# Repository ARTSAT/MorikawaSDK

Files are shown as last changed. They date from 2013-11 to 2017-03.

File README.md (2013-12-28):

MorikawaSDK
===========

An arduino base application programming environment for satellite's mission.

currently supported APIs:

```cpp
// singleton design
static & getInstance(void);

// memory environment and memory state
static TSTError getMemorySpec(MemorySpec* result);
static TSTError getMemoryInfo(MemoryInfo* result);
static TSTError getMemoryLog(MemoryInfo* result);
static void saveMemoryLog(void);

// self test
static TSTError getSelfTestLog(SelfTestLog* result);
static void eraseSelfTestLog(void);

// memory size information
static unsigned long getSizeEEPROM(void);
static unsigned long getSizeSharedMemory(void);
static unsigned long getSizeFRAM(void);
static unsigned long getSizeFlashROM(void);
static unsigned int getPageSizeEEPROM(void);
static unsigned int getPageSizeSharedMemory(void);
static unsigned int getPageSizeFRAM(void);
static unsigned int getPageSizeFlashROM(void);
static unsigned long getSectorSizeEEPROM(void);
static unsigned long getSectorSizeSharedMemory(void);
static unsigned long getSectorSizeFRAM(void);
static unsigned long getSectorSizeFlashROM(void);

// camera format information
static TSTError getCameraFormat(CameraType mode, CameraFormat* result);

// boot parameter
unsigned long getBootTime(void) const;
unsigned char getBootCount(void) const;
unsigned char getBootMode(void) const;

// peripheral parameter
TSTError getParamNote(NoteParam* result);
TSTError getParamMorse(MorseParam* result);
TSTError getParamDigitalker(DigitalkerParam* result);
TSTError getParamCamera(CameraParam* result);

// telemetry data
TSTError getTelemetryTime(TimeType type, unsigned long* result) const;
TSTError getTelemetryVoltage(VoltageType type, unsigned char* result) const;
TSTError getTelemetryVoltage(VoltageType type, double* result) const;
TSTError getTelemetryCurrent(CurrentType type, unsigned char* result) const;
TSTError getTelemetryCurrent(CurrentType type, double* result) const;
TSTError getTelemetryTemperature(TemperatureType type, unsigned char* result) const;
TSTError getTelemetryTemperature(TemperatureType type, double* result) const;
TSTError getTelemetryGyro(GyroType type, unsigned char* result) const;
TSTError getTelemetryGyro(GyroType type, double* result) const;
TSTError getTelemetryMagnet(MagnetType type, unsigned char* result) const;
TSTError getTelemetryMagnet(MagnetType type, double* result) const;

// FlashROM mode
TSTError setFlashROMEraseMode(bool param);
bool getFlashROMEraseMode(void) const;

// shared memory text setter and text getter
TSTError setText(TextType index, char const* text, int length = -1);
TSTError setTextPGM(TextType index, char const PROGMEM* text, int length = -1);
TSTError getText(TextType index, char* text, unsigned int length, int* result = NULL);

// peripheral LED device
TSTError setLED(LEDType index, unsigned char pwm);
unsigned char getLED(LEDType index) const;

// peripheral mode
TSTError setNoteBPM(int param = -1);
int getNoteBPM(void) const;
TSTError setMorseWPM(int param = -1);
int getMorseWPM(void) const;
TSTError setSpeakAsyncMode(bool param);
bool getSpeakAsyncMode(void) const;

// validation
bool isValid(void) const;
bool isValidSharedMemory(void) const;
bool isValidFRAM(void) const;
bool isValidFlashROM(void) const;
bool isValidLED(void) const;
bool isValidTone(void) const;
bool isValidDigitalker(void) const;
bool isValidCamera(void) const;

// status
TSTError isBusyDigitalker(bool* result) const;
bool hasTelemetryUpdate(void) const;
bool hasAbnormalShutdown(void) const;

// core function
TSTError setup(void);
void cleanup(void);
static void shutdown(void);
void loop(void);

// EEPROM
static TSTError writeEEPROM(unsigned long address, void const* data, unsigned int size, unsigned int* result = NULL);
static TSTError writeEEPROMPGM(unsigned long address, void const PROGMEM* data, unsigned int size, unsigned int* result = NULL);
static TSTError readEEPROM(unsigned long address, void* data, unsigned int size, unsigned int* result = NULL);
static TSTError formatEEPROM(void);

// Shared Memory
TSTError writeSharedMemory(unsigned long address, void const* data, unsigned int size, unsigned int* result = NULL);
TSTError writeSharedMemoryPGM(unsigned long address, void const PROGMEM* data, unsigned int size, unsigned int* result = NULL);
TSTError readSharedMemory(unsigned long address, void* data, unsigned int size, unsigned int* result = NULL);
TSTError formatSharedMemory(void);

// FRAM
TSTError writeFRAM(unsigned long address, void const* data, unsigned int size, unsigned int* result = NULL);
TSTError writeFRAMPGM(unsigned long address, void const PROGMEM* data, unsigned int size, unsigned int* result = NULL);
TSTError readFRAM(unsigned long address, void* data, unsigned int size, unsigned int* result = NULL);
TSTError formatFRAM(void);

// FlashROM
TSTError writeFlashROM(unsigned long address, void const* data, unsigned int size, unsigned int* result = NULL);
TSTError writeFlashROMPGM(unsigned long address, void const PROGMEM* data, unsigned int size, unsigned int* result = NULL);
TSTError readFlashROM(unsigned long address, void* data, unsigned int size, unsigned int* result = NULL);
TSTError formatFlashROM(void);

// note and morse
TSTError playFrequency(FrequencyType frequency, unsigned long duration);
TSTError playFrequency(FrequencySequence const* sequence, int length = -1);
TSTError playFrequencyPGM(FrequencySequence const PROGMEM* sequence, int length = -1);
TSTError playNote(NoteType note, DurationType duration, QualifierType qualifier = QUALIFIER_NONE);
TSTError playNote(NoteSequence const* sequence, int length = -1);
TSTError playNotePGM(NoteSequence const PROGMEM* sequence, int length = -1);
TSTError playMorse(NoteType note, char character);
TSTError playMorse(NoteType note, char const* sequence, int length = -1);
TSTError playMorsePGM(NoteType note, char const PROGMEM* sequence, int length = -1);

// digitalker
TSTError speakPhrase(char const* phrase, int length = -1);
TSTError speakPhrasePGM(char const PROGMEM* phrase, int length = -1);
TSTError waitPhrase(void);
TSTError stopPhrase(void);

// camera
TSTError snapshotCamera(CameraType mode, StorageType storage, unsigned long address, unsigned long size, unsigned long* result);

// data compression / decompression
TSTError freezeFastLZ(StorageType istorage, unsigned long iaddress, unsigned long isize, StorageType ostorage, unsigned long oaddress, unsigned long osize, StorageType wstorage, unsigned long waddress, unsigned long wsize, unsigned long* result);
TSTError meltFastLZ(StorageType istorage, unsigned long iaddress, unsigned long isize, StorageType ostorage, unsigned long oaddress, unsigned long osize, unsigned long* result);

// audio power control
TSTError enableAudioBus(void);
void disableAudioBus(void);
```

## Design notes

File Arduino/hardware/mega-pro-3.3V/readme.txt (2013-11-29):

Instructions to have the Mega Pro 3.3V show up in the Arduino device list. 
 
1) Download the latest mega_pro_3.3V zip file and extract it.	
2) You will need to be using a recent version of the Arduino environment, version 18 or later.
3) Create a 'hardware' directory inside your sketches folder. 
4) Copy the mega_pro_3.3V directory into the hardware directory.
5) Restart the Arduino software. New boards will appear in the Tools > Board menu.

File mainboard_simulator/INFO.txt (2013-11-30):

If you want to use MainBoard simulator, please see

https://github.com/ARTSAT/ground_station/tree/master/openFrameworks-osx/MainBoardSimulator

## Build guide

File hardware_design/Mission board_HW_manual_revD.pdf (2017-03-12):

# ARTSAT Mission board Developer’s Manual

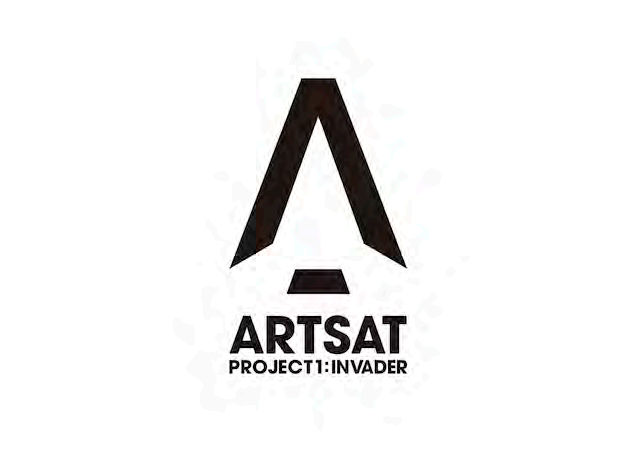
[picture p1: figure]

# Code name: MORIKAWA

# Flight Model

2017/03/12

## Kent Nakazawa (kent_n@outlook.com)

## ・INVADER 衛星(CO-77)の Arduino 互換ミッション機器

## ・Arduino IDE によるアプリケーション開発(MORIKAWA SDK)

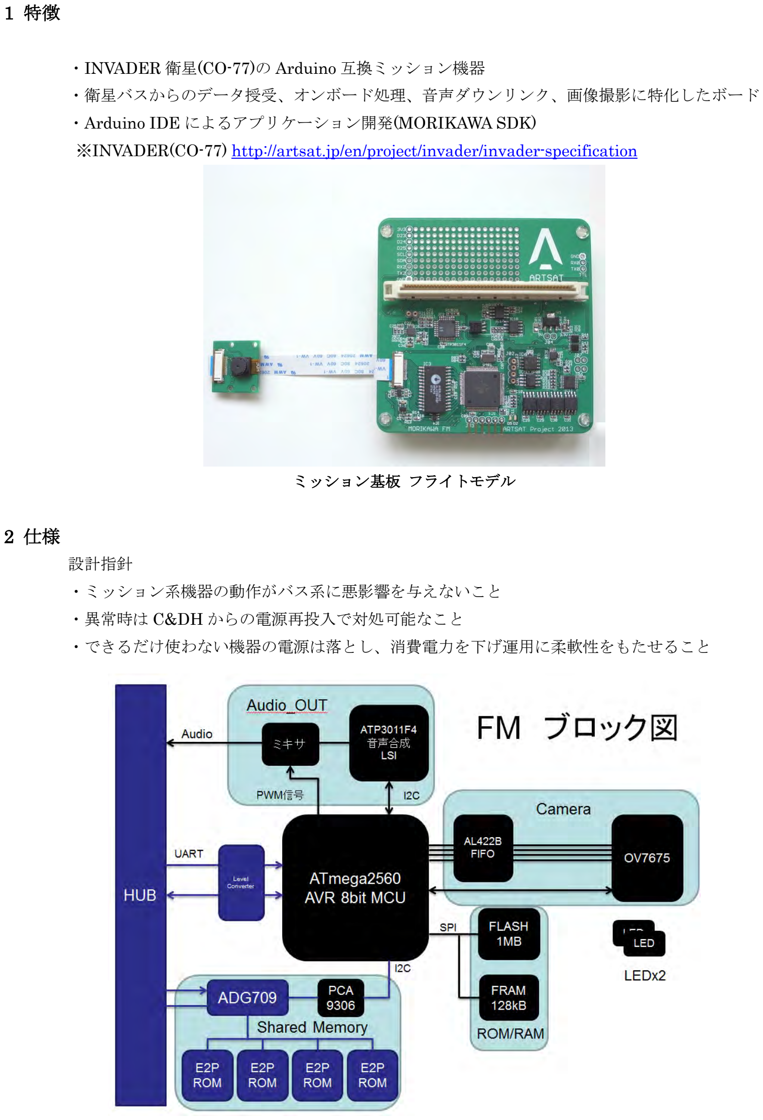
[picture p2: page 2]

1 特徴

・衛星バスからのデータ授受、オンボード処理、音声ダウンリンク、画像撮影に特化したボード

## ※INVADER(CO-77) http://artsat.jp/en/project/invader/invader-specification

ミッション基板 フライトモデル

2 仕様

設計指針
・ミッション系機器の動作がバス系に悪影響を与えないこと
・異常時は C&DH からの電源再投入で対処可能なこと

・できるだけ使わない機器の電源は落とし、消費電力を下げ運用に柔軟性をもたせること

## 2.1 MCU ・ATmega2560(RAM8kB,ROM256kB) 動作周波数 8MHz タイプ

・同期/非同期シリアル I2C_1ch, SPI_1ch,UART_4ch,
2.2 カメラモジュール
・OV7670 CMOS フライトモデルではレンズ一体型モジュールを使用。

## ・AL422B VGA FIFO ・12 / 24MHz クロック発振器 FM は 12MHzOSC

・ピン接続仕様は市販の FIFO 付きカメラモジュールと互換 ・カメラ用素子(モジュール、FIFO)の電源は未使用時に OFF

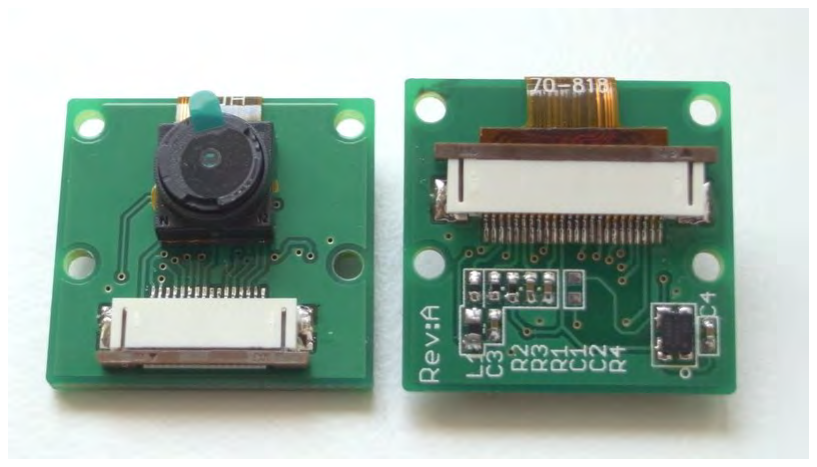
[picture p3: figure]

カメラモジュール 子基板

## 2.3 音声合成 LSI ATP3011F4 日本語音声合成 IC 通信: I2C

## 2.4 不揮発性 RAM ・SPI FRAM 128kB FM25V10

・消費電流が少なく、1 バイト単位でのアクセスが可能な不揮発性メモリ ・M25P80 とピン互換
・Flash や EEPROM へ保存する前のバッファメモリ等
2.5 大容量 ROM ストレージ

## ・SPI Flash メモリ 1MB M25P80

・Flash メモリ。画像、処理結果データの保存先として確保 2.8 共有メモリ

## ・EEPROM(24LC1025) x4 個 電源ドメインは 5V 系

・Main 系が、マルチプレクサ ADG709 によりアクセス権を設定 (LOW=バス系、HIGH=ミッション 系 切り替えラインはプルダウン) し、Mission 側に切り替え権は無い ・基板上のジャンパピンにより単独でアクセス可能 (開発用機能)

バス接続時、フライト時はジャンパピンを外すこと

## 2.6 LED x2 ・ATmega2560 へ接続(正論理)

・主にステータス確認用

2.7 INVADER バス接続用インターフェース

## ・バスは 5V 系 Mission は 3.3V 系

・共有メモリ、バス温度センサは 5V 系、C&DH 電源で動作 ・2 電源バスバッファにより電圧変換(UART、共有メモリ I2C)

3 開発環境

3.1 ソフトウェア開発環境

機器一覧

## ・USB-Serial 変換器/プログラマ https://www.sparkfun.com/products/9873

・リセット(DTR)がついた TTL レベル UART 接続 5V 供給できるもの

## ・PC/Mac/Linux ・既製品の Arduino ボード（ArduinoISP として使用）

・Arduino IDE(1.0.6) ※最新の IDE ではボード定義の追加が難しいため、1.0.6 での構築を推奨

## https://www.arduino.cc/en/Main/OldSoftwareReleases#previous

## 3.2 Arduino IDE 設定 (ArduinoIDE バージョン 1.0.6)

・Arduino IDE をインストールする
・MorikawaSDK に必要なファイルをダウンロードする。

## https://github.com/ARTSAT/MorikawaSDK をダウンロードし、 Arduino ディレクトリ内の二つのディレクトリ（libraries, hardware）を ArduinoIDE のスケッチ保存フォルダ（デフォルトでは documents/Arduino 内）に

入れる。
・ArduinoIDE を立ち上げ、ツール/board からボード選択リストを開き、

## Mega Pro 2560V 3.3V を選択

3.3 AVR ブートローダ設定

## ATmega2560 8MHz 版ブートローダの設定

・MORIKAWA にシリアルブートローダーを設定することで、シリアルポートからスケッチをアップロ

ードできる
・書き込みは ICSP という方式で、Arduino ボードをライターとして使用する手法を使う ・ICSP 用 4 ピン端子(J02 )を J02 に設けており、Arduino ISP 等で書き込みが可能

書き込みの流れは以下のサイトを参考にする

## https://www.arduino.cc/en/Tutorial/ArduinoISP Morikawa での各種端子の位置は、ピンアサイン表（MISSION_board_HW_layout.pdf）を参照

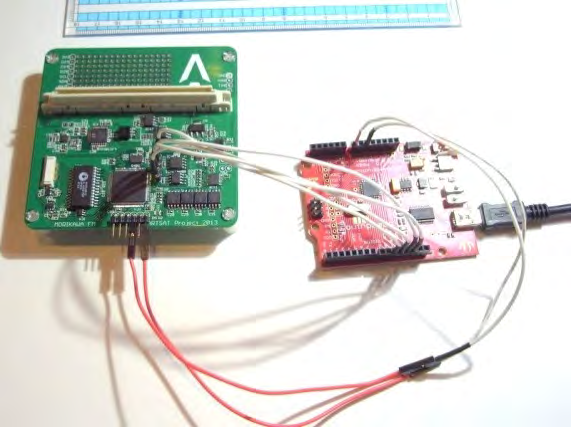
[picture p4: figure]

Arduino ISP によるブートローダーの書き込み

簡易手順
・まず、ライター用の Arduino ボードの設定で、スケッチ例から ArduinoISP を選択し、書き込む ・次に、ターゲットとなるボードの設定（mega-pro-3.3V）を選択する
・ライター用ボードの SPI 端子、リセット端子を、MORIKAWA ボードの J02 端子に接続する ・MORIKAWA への電源投入を行う。（5V 程度）
・IDE のツール/書き込み装置 にて、Arduino as ISP が選択されているか確認する ・ツール/ブートローダーを書き込む をクリックし、書き込みを行う

（結線や設定が間違っている場合、エラーが発生する）

## 3.4 Morikawa Software 書き込み、動作確認 Arduino IDE の設定 ボード設定: mega pro 2560V 3.3V

ポート：接続した USB シリアルポートの COM 番号

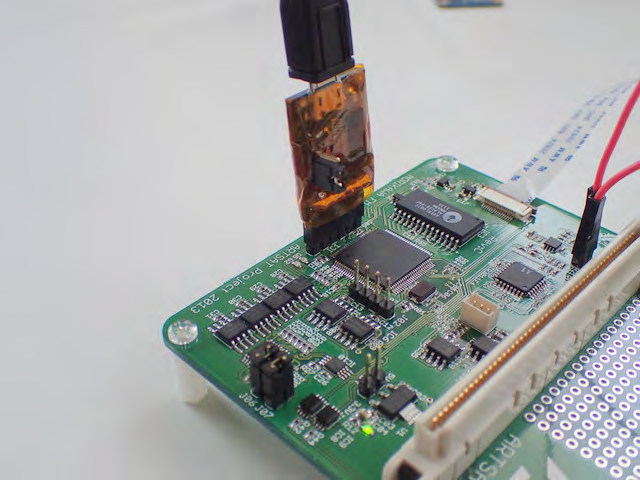
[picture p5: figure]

USB シリアル変換器の接続
・ファイル/スケッチの例から、MorikawaSDK を選択する。

・動作確認する場合は、

## DebugTest(ボードの動作確認)

HelloSpace(デジトーカーと音声のテスト)

を選択し、書き込んで単体で動作を確認できる
音声出力は、ジャンパ線をモノラルのオーディオジャックに接続すれば、ヘッドホンやスピ ーカーに直接繋いで確認できる。

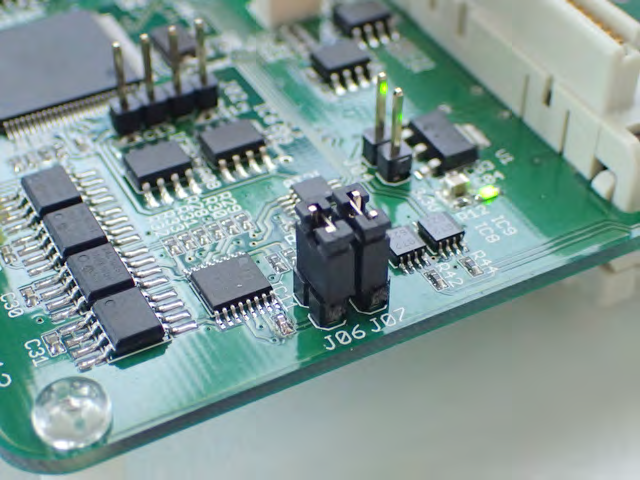
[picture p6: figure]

単体での動作確認の際は、I2C の共有メモリ部のジャンパピンを二つとも図のように接続する。

3.5 連携開発時の注意

・Invader 衛星に組み込んだ後は、USB シリアル変換器から電源を入力しないよう 6 ピン端子から電 源ピンを除去する。MORIKAWA の電源は Invader のシステムから投入
・ICSP 書き込みは 5V 系のボードからでも OK ・念のためその日の最初の電源投入前に、電源ライン（J04）がショートしていないか調べる ・I2C 機器をテストする場合、ボード単体では 2 つのジャンパピンをショートさせる必要がある （単体でオープン状態だと、音声合成 IC と共有メモリにアクセスできない） 逆に、Main と接続したり、連系試験を行う場合は、ジャンパピンを必ず取り除くこと

4 電気特性

・消費電流

## case1, 5V 系なし、周辺機器設定なし、UART 115k で 100ms ごとに送信: 9mA case2, カメラ系 ON 時: 約 60mA (数秒間)

5 設計情報

## Power Domain

基板上の回路は 3 つの電源ドメインから構成される

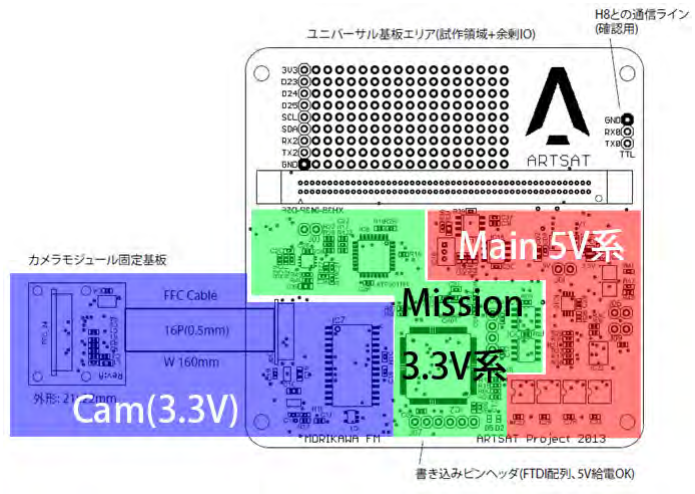
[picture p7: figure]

5V 系は Main 基板の延長となり、Main の電力(5V)をもらい常時通電している。
ミッションは 3.3V 系であり、Main の指令で、衛星の電源系により電源投入される

カメラ系はアプリによって、ミッション系から電源投入される。消費電力を下げるため、撮影終了とともにカメ ラモジュールの内部クロックを下限値まで落とし、FIFO の読み出し時の電力削減を行っている

※ユニバーサルエリアは試作部品追加が可能なように設けた すぐそばに電源ライン、AVR の UART 1ch,I2C バス、デジタル I/Ox3 を引き出した シルク印刷のピン番号は ArduinoAPI のピン番号となっている

## (参照 MISSION_FM_HW_layout)

FM 品の修正)

フライトモデルについて、搭載前の基板への変更点
・カメラ回路: VSYNC と WRST が繋がっていない 解決策: MCU 端子をハンダブリッジ(35,36 番ピン) ・回路修正: リセットライン ATMEGA2560 と ATP3011F4 間の接続を分離(パターンカット) ・回路修正: C01、R07、R43 は未実装
・回路図中の LED の極性が逆（そのまま実装すると光らない）

5 資料

## Artsat GitHub https://github.com/ARTSAT/MorikawaSDK

6 設計データリビジョン

・フライトモデル: Rev:A (基板上での修正)
・2015/03/24 | Rev:C (リワーク内容の反映、部品削除、部品定数の変更) Rev:A とソフトウェア互換あり
・2017 March | Rev:D (LED の極性の反映、書き込み手順の追加)

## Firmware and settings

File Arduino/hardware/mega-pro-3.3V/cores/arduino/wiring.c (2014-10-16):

/*
  wiring.c - Partial implementation of the Wiring API for the ATmega8.
  Part of Arduino - http://www.arduino.cc/

  Copyright (c) 2005-2006 David A. Mellis

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
  $Id: wiring.c,v 1.1 2013/11/29 17:05:39 administrator Exp $
*/

#include "wiring_private.h"

// the prescaler is set so that timer0 ticks every 64 clock cycles, and the
// the overflow handler is called every 256 ticks.
#define MICROSECONDS_PER_TIMER0_OVERFLOW (clockCyclesToMicroseconds(64 * 256))

// the whole number of milliseconds per timer0 overflow
#define MILLIS_INC (MICROSECONDS_PER_TIMER0_OVERFLOW / 1000)

// the fractional number of milliseconds per timer0 overflow. we shift right
// by three to fit these numbers into a byte. (for the clock speeds we care
// about - 8 and 16 MHz - this doesn't lose precision.)
#define FRACT_INC ((MICROSECONDS_PER_TIMER0_OVERFLOW % 1000) >> 3)
#define FRACT_MAX (1000 >> 3)

volatile unsigned long timer0_overflow_count = 0;
volatile unsigned long timer0_millis = 0;
static unsigned char timer0_fract = 0;

#if defined(__AVR_ATtiny24__) || defined(__AVR_ATtiny44__) || defined(__AVR_ATtiny84__)
SIGNAL(TIM0_OVF_vect)
#else
SIGNAL(TIMER0_OVF_vect)
#endif
{
	// copy these to local variables so they can be stored in registers
	// (volatile variables must be read from memory on every access)
	unsigned long m = timer0_millis;
	unsigned char f = timer0_fract;

	m += MILLIS_INC;
	f += FRACT_INC;
	if (f >= FRACT_MAX) {
		f -= FRACT_MAX;
		m += 1;
	}

	timer0_fract = f;
	timer0_millis = m;
	timer0_overflow_count++;
}

unsigned long millis()
{
	unsigned long m;
	uint8_t oldSREG = SREG;

	// disable interrupts while we read timer0_millis or we might get an
	// inconsistent value (e.g. in the middle of a write to timer0_millis)
	cli();
	m = timer0_millis;
	SREG = oldSREG;

	return m;
}

unsigned long micros() {
	unsigned long m;
	uint8_t oldSREG = SREG, t;
	
	cli();
	m = timer0_overflow_count;
#if defined(TCNT0)
	t = TCNT0;
#elif defined(TCNT0L)
	t = TCNT0L;
#else
	#error TIMER 0 not defined
#endif

  
#ifdef TIFR0
	if ((TIFR0 & _BV(TOV0)) && (t < 255))
		m++;
#else
	if ((TIFR & _BV(TOV0)) && (t < 255))
		m++;
#endif

	SREG = oldSREG;
	
	return ((m << 8) + t) * (64 / clockCyclesPerMicrosecond());
}

void delay(unsigned long ms)
{
	uint16_t start = (uint16_t)micros();

	while (ms > 0) {
		if (((uint16_t)micros() - start) >= 1000) {
			ms--;
			start += 1000;
		}
	}
}

/* Delay for the given number of microseconds.  Assumes a 8 or 16 MHz clock. */
void delayMicroseconds(unsigned int us)
{
	// calling avrlib's delay_us() function with low values (e.g. 1 or
	// 2 microseconds) gives delays longer than desired.
	//delay_us(us);
#if F_CPU >= 20000000L
	// for the 20 MHz clock on rare Arduino boards

	// for a one-microsecond delay, simply wait 2 cycle and return. The overhead
	// of the function call yields a delay of exactly a one microsecond.
	__asm__ __volatile__ (
		"nop" "\n\t"
		"nop"); //just waiting 2 cycle
	if (--us == 0)
		return;

	// the following loop takes a 1/5 of a microsecond (4 cycles)
	// per iteration, so execute it five times for each microsecond of
	// delay requested.
	us = (us<<2) + us; // x5 us

	// account for the time taken in the preceeding commands.
	us -= 2;

#elif F_CPU >= 16000000L
	// for the 16 MHz clock on most Arduino boards

	// for a one-microsecond delay, simply return.  the overhead
	// of the function call yields a delay of approximately 1 1/8 us.
	if (--us == 0)
		return;

	// the following loop takes a quarter of a microsecond (4 cycles)
	// per iteration, so execute it four times for each microsecond of
	// delay requested.
	us <<= 2;

	// account for the time taken in the preceeding commands.
	us -= 2;
#else
	// for the 8 MHz internal clock on the ATmega168

	// for a one- or two-microsecond delay, simply return.  the overhead of
	// the function calls takes more than two microseconds.  can't just
	// subtract two, since us is unsigned; we'd overflow.
	if (--us == 0)
		return;
	if (--us == 0)
		return;

	// the following loop takes half of a microsecond (4 cycles)
	// per iteration, so execute it twice for each microsecond of
	// delay requested.
	us <<= 1;
    
	// partially compensate for the time taken by the preceeding commands.
	// we can't subtract any more than this or we'd overflow w/ small delays.
	us--;
#endif

	// busy wait
	__asm__ __volatile__ (
		"1: sbiw %0,1" "\n\t" // 2 cycles
		"brne 1b" : "=w" (us) : "0" (us) // 2 cycles
	);
}

void init()
{
	// this needs to be called before setup() or some functions won't
	// work there
	sei();
	
	// on the ATmega168, timer 0 is also used for fast hardware pwm
	// (using phase-correct PWM would mean that timer 0 overflowed half as often
	// resulting in different millis() behavior on the ATmega8 and ATmega168)
#if defined(TCCR0A) && defined(WGM01)
	sbi(TCCR0A, WGM01);
	sbi(TCCR0A, WGM00);
#endif  

	// set timer 0 prescale factor to 64
#if defined(__AVR_ATmega128__)
	// CPU specific: different values for the ATmega128
	sbi(TCCR0, CS02);
#elif defined(TCCR0) && defined(CS01) && defined(CS00)
	// this combination is for the standard atmega8
	sbi(TCCR0, CS01);
	sbi(TCCR0, CS00);
#elif defined(TCCR0B) && defined(CS01) && defined(CS00)
	// this combination is for the standard 168/328/1280/2560
	sbi(TCCR0B, CS01);
	sbi(TCCR0B, CS00);
#elif defined(TCCR0A) && defined(CS01) && defined(CS00)
	// this combination is for the __AVR_ATmega645__ series
	sbi(TCCR0A, CS01);
	sbi(TCCR0A, CS00);
#else
	#error Timer 0 prescale factor 64 not set correctly
#endif

	// enable timer 0 overflow interrupt
#if defined(TIMSK) && defined(TOIE0)
	sbi(TIMSK, TOIE0);
#elif defined(TIMSK0) && defined(TOIE0)
	sbi(TIMSK0, TOIE0);
#else
	#error	Timer 0 overflow interrupt not set correctly
#endif

	// timers 1 and 2 are used for phase-correct hardware pwm
	// this is better for motors as it ensures an even waveform
	// note, however, that fast pwm mode can achieve a frequency of up
	// 8 MHz (with a 16 MHz clock) at 50% duty cycle

#if defined(TCCR1B) && defined(CS11) && defined(CS10)
	TCCR1B = 0;

	// set timer 1 prescale factor to 64
	sbi(TCCR1B, CS11);
#if F_CPU >= 8000000L
	sbi(TCCR1B, CS10);
#endif
#elif defined(TCCR1) && defined(CS11) && defined(CS10)
	sbi(TCCR1, CS11);
#if F_CPU >= 8000000L
	sbi(TCCR1, CS10);
#endif
#endif
	// put timer 1 in 8-bit phase correct pwm mode
#if defined(TCCR1A) && defined(WGM10)
	sbi(TCCR1A, WGM10);
#elif defined(TCCR1)
	#warning this needs to be finished
#endif

	// set timer 2 prescale factor to 64
#if defined(TCCR2) && defined(CS22)
	sbi(TCCR2, CS22);
#elif defined(TCCR2B) && defined(CS22)
	sbi(TCCR2B, CS22);
#else
	#warning Timer 2 not finished (may not be present on this CPU)
#endif

	// configure timer 2 for phase correct pwm (8-bit)
#if defined(TCCR2) && defined(WGM20)
	sbi(TCCR2, WGM20);
#elif defined(TCCR2A) && defined(WGM20)
	sbi(TCCR2A, WGM20);
#else
	#warning Timer 2 not finished (may not be present on this CPU)
#endif
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

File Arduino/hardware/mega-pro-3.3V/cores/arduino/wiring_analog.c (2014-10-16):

/*
  wiring_analog.c - analog input and output
  Part of Arduino - http://www.arduino.cc/

  Copyright (c) 2005-2006 David A. Mellis

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
  Modified 28 September 2010 by Mark Sproul

  $Id: wiring_analog.c,v 1.1 2013/11/29 17:05:39 administrator Exp $
*/

#include "wiring_private.h"
#include "pins_arduino.h"

uint8_t analog_reference = DEFAULT;

void analogReference(uint8_t mode)
{
	// can't actually set the register here because the default setting
	// will connect AVCC and the AREF pin, which would cause a short if
	// there's something connected to AREF.
	analog_reference = mode;
}

int analogRead(uint8_t pin)
{
	uint8_t low, high;

#if defined(__AVR_ATmega1280__) || defined(__AVR_ATmega2560__)
	if (pin >= 54) pin -= 54; // allow for channel or pin numbers
#elif defined(__AVR_ATmega32U4__)
	if (pin >= 18) pin -= 18; // allow for channel or pin numbers
#elif defined(__AVR_ATmega1284__)
	if (pin >= 24) pin -= 24; // allow for channel or pin numbers
#else
	if (pin >= 14) pin -= 14; // allow for channel or pin numbers
#endif
	
#if defined(__AVR_ATmega32U4__)
	pin = analogPinToChannel(pin);
	ADCSRB = (ADCSRB & ~(1 << MUX5)) | (((pin >> 3) & 0x01) << MUX5);
#elif defined(ADCSRB) && defined(MUX5)
	// the MUX5 bit of ADCSRB selects whether we're reading from channels
	// 0 to 7 (MUX5 low) or 8 to 15 (MUX5 high).
	ADCSRB = (ADCSRB & ~(1 << MUX5)) | (((pin >> 3) & 0x01) << MUX5);
#endif
  
	// set the analog reference (high two bits of ADMUX) and select the
	// channel (low 4 bits).  this also sets ADLAR (left-adjust result)
	// to 0 (the default).
#if defined(ADMUX)
	ADMUX = (analog_reference << 6) | (pin & 0x07);
#endif

	// without a delay, we seem to read from the wrong channel
	//delay(1);

#if defined(ADCSRA) && defined(ADCL)
	// start the conversion
	sbi(ADCSRA, ADSC);

	// ADSC is cleared when the conversion finishes
	while (bit_is_set(ADCSRA, ADSC));

	// we have to read ADCL first; doing so locks both ADCL
	// and ADCH until ADCH is read.  reading ADCL second would
	// cause the results of each conversion to be discarded,
	// as ADCL and ADCH would be locked when it completed.
	low  = ADCL;
	high = ADCH;
#else
	// we dont have an ADC, return 0
	low  = 0;
	high = 0;
#endif

	// combine the two bytes
	return (high << 8) | low;
}

// Right now, PWM output only works on the pins with
// hardware support.  These are defined in the appropriate
// pins_*.c file.  For the rest of the pins, we default
// to digital output.
void analogWrite(uint8_t pin, int val)
{
	// We need to make sure the PWM output is enabled for those pins
	// that support it, as we turn it off when digitally reading or
	// writing with them.  Also, make sure the pin is in output mode
	// for consistenty with Wiring, which doesn't require a pinMode
	// call for the analog output pins.
	pinMode(pin, OUTPUT);
	if (val == 0)
	{
		digitalWrite(pin, LOW);
	}
	else if (val == 255)
	{
		digitalWrite(pin, HIGH);
	}
	else
	{
		switch(digitalPinToTimer(pin))
		{
			// XXX fix needed for atmega8
			#if defined(TCCR0) && defined(COM00) && !defined(__AVR_ATmega8__)
			case TIMER0A:
				// connect pwm to pin on timer 0
				sbi(TCCR0, COM00);
				OCR0 = val; // set pwm duty
				break;
			#endif

			#if defined(TCCR0A) && defined(COM0A1)
			case TIMER0A:
				// connect pwm to pin on timer 0, channel A
				sbi(TCCR0A, COM0A1);
				OCR0A = val; // set pwm duty
				break;
			#endif

			#if defined(TCCR0A) && defined(COM0B1)
			case TIMER0B:
				// connect pwm to pin on timer 0, channel B
				sbi(TCCR0A, COM0B1);
				OCR0B = val; // set pwm duty
				break;
			#endif

			#if defined(TCCR1A) && defined(COM1A1)
			case TIMER1A:
				// connect pwm to pin on timer 1, channel A
				sbi(TCCR1A, COM1A1);
				OCR1A = val; // set pwm duty
				break;
			#endif

			#if defined(TCCR1A) && defined(COM1B1)
			case TIMER1B:
				// connect pwm to pin on timer 1, channel B
				sbi(TCCR1A, COM1B1);
				OCR1B = val; // set pwm duty
				break;
			#endif

			#if defined(TCCR2) && defined(COM21)
			case TIMER2:
				// connect pwm to pin on timer 2
				sbi(TCCR2, COM21);
				OCR2 = val; // set pwm duty
				break;
			#endif

			#if defined(TCCR2A) && defined(COM2A1)
			case TIMER2A:
				// connect pwm to pin on timer 2, channel A
				sbi(TCCR2A, COM2A1);
				OCR2A = val; // set pwm duty
				break;
			#endif

			#if defined(TCCR2A) && defined(COM2B1)
			case TIMER2B:
				// connect pwm to pin on timer 2, channel B
				sbi(TCCR2A, COM2B1);
				OCR2B = val; // set pwm duty
				break;
			#endif

			#if defined(TCCR3A) && defined(COM3A1)
			case TIMER3A:
				// connect pwm to pin on timer 3, channel A
				sbi(TCCR3A, COM3A1);
				OCR3A = val; // set pwm duty
				break;
			#endif

			#if defined(TCCR3A) && defined(COM3B1)
			case TIMER3B:
				// connect pwm to pin on timer 3, channel B
				sbi(TCCR3A, COM3B1);
				OCR3B = val; // set pwm duty
				break;
			#endif

			#if defined(TCCR3A) && defined(COM3C1)
			case TIMER3C:
				// connect pwm to pin on timer 3, channel C
				sbi(TCCR3A, COM3C1);
				OCR3C = val; // set pwm duty
				break;
			#endif

			#if defined(TCCR4A)
			case TIMER4A:
				//connect pwm to pin on timer 4, channel A
				sbi(TCCR4A, COM4A1);
				#if defined(COM4A0)		// only used on 32U4
				cbi(TCCR4A, COM4A0);
				#endif
				OCR4A = val;	// set pwm duty
				break;
			#endif
			
			#if defined(TCCR4A) && defined(COM4B1)
			case TIMER4B:
				// connect pwm to pin on timer 4, channel B
				sbi(TCCR4A, COM4B1);
				OCR4B = val; // set pwm duty
				break;
			#endif

			#if defined(TCCR4A) && defined(COM4C1)
			case TIMER4C:
				// connect pwm to pin on timer 4, channel C
				sbi(TCCR4A, COM4C1);
				OCR4C = val; // set pwm duty
				break;
			#endif
				
			#if defined(TCCR4C) && defined(COM4D1)
			case TIMER4D:				
				// connect pwm to pin on timer 4, channel D
				sbi(TCCR4C, COM4D1);
				#if defined(COM4D0)		// only used on 32U4
				cbi(TCCR4C, COM4D0);
				#endif
				OCR4D = val;	// set pwm duty
				break;
			#endif

							
			#if defined(TCCR5A) && defined(COM5A1)
			case TIMER5A:
				// connect pwm to pin on timer 5, channel A
				sbi(TCCR5A, COM5A1);
				OCR5A = val; // set pwm duty
				break;
			#endif

			#if defined(TCCR5A) && defined(COM5B1)
			case TIMER5B:
				// connect pwm to pin on timer 5, channel B
				sbi(TCCR5A, COM5B1);
				OCR5B = val; // set pwm duty
				break;
			#endif

			#if defined(TCCR5A) && defined(COM5C1)
			case TIMER5C:
				// connect pwm to pin on timer 5, channel C
				sbi(TCCR5A, COM5C1);
				OCR5C = val; // set pwm duty
				break;
			#endif

			case NOT_ON_TIMER:
			default:
				if (val < 128) {
					digitalWrite(pin, LOW);
				} else {
					digitalWrite(pin, HIGH);
				}
		}
	}
}

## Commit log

2013-11-29 initially added
    [MISSION_FM1.brd, MISSION_FM1.sch, OV_FPC.brd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]
2013-12-16 support camera device
2013-12-22 improve camera support
2014-05-10 fix I2C reading bug
2014-10-17 added enable / disable PowerBus
2015-03-09 Update Morikawa HW files
    [MISSION_FM1.brd, MISSION_FM1.sch]
2015-03-24 update Morikawa HW files
    Rev:C
    [MISSION_FM1.brd, MISSION_FM1.sch]
2017-03-12 fix schematic bug and instruction manual
    MORIKAWA_FM: invert SMD LED direction.
    Hardware manual: add instruction for IDE setup
    [MISSION_FM1.brd, MISSION_FM1.sch]

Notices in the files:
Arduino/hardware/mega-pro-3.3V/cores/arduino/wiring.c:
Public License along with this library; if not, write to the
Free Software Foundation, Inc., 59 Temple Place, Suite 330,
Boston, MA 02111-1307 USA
